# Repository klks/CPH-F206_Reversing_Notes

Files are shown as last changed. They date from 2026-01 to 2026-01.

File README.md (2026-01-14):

# How it started
Late 2025, I came across a Taobao listing that was selling a UHF RFID Reader for less than 10USD, this is fairly uncommon as most readers go for 15+usd onwards. I decided to buy one to add to my reader collection. (I ended up buying 6 units)<br>

<br>

This UHF RFID reader is sold under the model numbers below (with Taobao links)

- [CPH-F206](https://item.taobao.com/item.htm?id=904352296655&skuId=5763416697782)
- [TC-C206](https://item.taobao.com/item.htm?id=820590020134&skuId=5696639435762)
- [BYH-206](https://detail.tmall.com/item.htm?id=986978403603&skuId=5952377616135)

Searching online based on provided software, and screenshots, I was able to track down the company that made the software to [Cykeo](https://www.cykeorfid.com/), they are a company that specializes in making industrial rfid readers and antennas.

# Reader Software
The reader comes with its own software and SDK, and is able to output in multiple formats including Wiegand, Modbus, as well as emulating a USB Keyboard.<br>
<br>
<br>

# PCB Screenshot
Cracking open the reader, we are greeted with a 30mm x 30mm PCB soldered to a another PCB that provides a USB-C connector, a buzzer, and some led's, to keep the PCB compact, 0603 SMD components were used.<br>
<br>

Taking a closer look at the front, we see the MCU and an unknown RF chip has their markings lasered off, and the back has descriptions on what each pin does, what catches my eye is the SWDIO and SWCLK pins, this means theres Serial Wire Debug capabilities, and a chance to dump firmware.<br>
<br>
<br>

# MCU Identification & Firmware Dumping
Before we can attempt to dump the firmware, we'd need to try to figure out what MCU is used, and lucky for us when plugging in the reader the device identifies itself as a N32g43xCustom HID, this led me to believe that the MCU was a [N32G435](https://nsing.com.sg/product/General/cortexm4/N32G435/)

Connecting the SWD header to a J-LINK, setting up its parameters, and attempting to read the firmware, I was able to get a successful dump. Usually MCU's have code readout protection which prevents the downloading of flash contents, the manufacturer did not turn this feature on.

# Firmware Reversing
The firmware can now be thrown into IDA/Ghidra for analysis, using the strings within, around 70% of the firmware can be mapped back to the N32G43x SDK and example implementation found on github. From within the firmware, the RF chip can be identified, they are using an [Si4463](https://www.silabs.com/wireless/proprietary/ezradiopro-sub-ghz-ics/device.si4463?tab=specs) Transceiver chip that supports the ISM band.

<br>
The reversing of the firmware is left as an exercise for the user and will not be covered here.

# PCB Reverse Engineering
The reversing of the PCB would not be possible if the firmware dump was not successful, now that we have the firmware, my next goal is to recreate the PCB but using larger 0805 SMD components.

With PCB reversing, the first steps are component identification, using a hot-plate, components were removed one by one, and their values recorded.<br>

<br>

When dealing with small value components like inductors and capacitors, a Nano-VNA can be used to identify their values.<br>

<br>

# Parts Identification
Identification of parts took a while as finding parts with the same name was challenging. Using part numbers, a multimeter, a component tester, an oscilloscope, image searching and pouring over datasheets helped find most of the components.<br>

<br>

| Marking | Name | Notes |
| --- | ---| --- |
| N32G435 | | MCU <br> [Datasheet](https://www.nsing.com.sg/uploads/DS/EN_DS_N32G435.pdf) |
| Si4463 | | RF Transceiver <br> [Datasheet](https://www.silabs.com/documents/public/data-sheets/Si4463-61-60-C.pdf)|
| 87t | Planar Schottky barrier diode |  [1PS70SB84](https://assets.nexperia.com/documents/data-sheet/1PS70SB82_84_85_86.pdf) (Obsolete), the closest is [BAT54S](https://assets.nexperia.com/documents/data-sheet/BAT54S.pdf) |
| 1F | 45 V, 100 mA NPN/NPN general-purpose transistor | [Datasheet](https://assets.nexperia.com/documents/data-sheet/BC847BS.pdf) |
| -V4 | 2-ch, 1.65-V to 5.5-V inverters | [SN74LVC2G04](https://www.ti.com/lit/ds/symlink/sn74lvc2g04.pdf) |
| AM | NPN switching transistor | [MMBT3904](https://www.onsemi.com/pdf/datasheet/mmbt3904wt1-d.pdf) |
| G4B | RF Switching Diode | No exact match found, the closest is [BAV70](https://assets.nexperia.com/documents/data-sheet/BAV70.pdf)
| N933 | 500mA uCap Ultra-Low Dropout, High PSRR LDO Regulator | [Datasheet](https://ww1.microchip.com/downloads/aemDocuments/documents/OTH/ProductDocuments/DataSheets/500mA-uCap-Ultra-Low-Dropout-Regulator-with-High-PSRR-DS20005876B.pdf) |

For the Si4463 matching and filter network, the datasheet was used to identify the nominal values.

<br>

# Sanding PCB
After the components and their positions have been identified, the solder mask of the PCB is stripped using a 200-600 grit sandpaper to expose the front and back copper layers. This PCB is 4 layers and is 1mm thick.

<br>
<br>

# Tracing PCB
Next using high resolution images, Inkscape, and a multimeter, the traces of the PCB and its via's are drawn in separate layers<br>
This step also maps the MCU and RF pins, an overlay from the datasheet is added for pin identification. The position and values of components measured earlier are also noted, grounds and power lines (5V, 3V3) are color coded.<br>

<br>

<br>

# Reversing PCB & Schematic
Using KiCad, the schematic is then redrawn with their component values. In this step, the component names from KiCad are mapped back to the PCB Trace in Inkscape. Some modifications were made around the USB-C and 3V3 power regulators circuit.

<br>

Schematics are released in the schematic directory of this repo.

# Impedance Matching of RF Trace
When recreating the PCB, KiCad's Calculator Tools and JLCPCB's Capabilities are used to calculate trace width and spacing for the RF trace line.

<br>
<br>

# Ordering & Testing PCB
After weeks of tracing and schematic drawing, PCB's are sent for fabrication. When placing components, i mimicked the layout of the original board, this was done to make circuit debugging easier<br>
<br>
Below is a size comparison of the original and recreated PCB.<br>
<br>
After soldering all the components, the original MCU was soldered on for testing. In the first attempt, the reader was not picking up any tags.<br>
Going back to the drawing board, a few components had to be re-measured from another working reader and a few mistakes were identified. At this point an oscilloscope was used to debug the circuit using references from a functional reader. After fixing mis-typed components and much experimenting, the reader works!.<br>
<br>
One area that needs to be studied more is the matching network and filter sections as the current PCB isn't as fast/sensitive enough at picking up tags vs the original reader.<br>
In v0.2 of the schematic, additional capacitors were added to the 5V rail. Also fixed incorrectly measured value for some components.<br>

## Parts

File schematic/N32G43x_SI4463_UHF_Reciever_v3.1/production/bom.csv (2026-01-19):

Designator | Footprint | Quantity | Value | LCSC Part #
C1, C14, C41, C42, C58 | 0805 | 5 | 100pF
C10, C12, C15, C18, C30, C34, C4, C7 | 0805 | 8 | 2.2nF
C11, C27, C40, C5, C55, C56, C6, C63, C8 | 0805 | 9 | 100nF
C13, C17, C24, C32 | 0805 | 4 | 12pF
C16, C23, C31 | 0805 | 3 | 20pF
C19, C20, C22, C28, C3, C36, C38, C46, C47, C48, C49, C50, C53, C54, C9 | 0805 | 15 | 10uF
C2 | 0805 | 1 | 3.2pF
C21, C37, C51, C52 | 0805 | 4 | 24pF
C25, C29, C33 | 0805 | 3 | 10nF
C26, C35 | 0805 | 2 | 1uF
C39 | 0805 | 1 | 1nF
C43, C44 | 0805 | 2 | 2pF
C45 | 0805 | 1 | 3.3pF
C57, C59, C60, C61, C62 | 1206 | 5 | 10uF
D1, D2 | SOT-23-3_L2.9-W1.6-P1.90-LS2.8-BR | 2 | BAT54S
D3, D4 | 0805 | 2 | LED
D5 | SOT-23-3_L2.9-W1.6-P1.90-LS2.8-BR | 1 | BAR6405
F1 | 0805 | 1 | 6V 0.75A
J1 | IPEX-SMD_BWIPX-1-001E | 1 | U.FL | C5137195
J2, USART1, USART2 | PinHeader_1x04_P2.54mm_Vertical | 3 | Conn_01x04_Socket
J3 | USB-C-SMD_TYPE-C-6PIN-2MD-073 | 1 | USB_C_Receptacle_USB2.0_16P | C2765186
J4 | SolderJumper-2_P1.3mm_Open_RoundedPad1.0x1.5mm | 1 | EN_BUZZ
J5 | PinHeader_1x03_P2.54mm_Vertical | 1 | Conn_01x03_Socket
L1, L2, L5 | 0805 | 3 | 12nH
L3, L4 | 0805 | 2 | 10nH
L6 | 0805 | 1 | 100nH
L7 | 0805 | 1 | 20uH
Q1, Q3, Q4, Q5, Q6, Q7 | SOT-363_SC-70-6 | 6 | BC847BS | C41375126
Q10, Q11, Q2, Q9 | Q_SOT-23 | 4 | MMBT3904 | C7420353
R1, R2, R24, R42, R6 | 0805 | 5 | 1.5k
R10, R7 | 0805 | 2 | R
R11, R12, R18, R19 | 0805 | 4 | 750
R13, R14 | 0805 | 2 | 2k
R15, R17, R30, R40, R41 | 0805 | 5 | 5.1k
R16, R22, R31 | 0805 | 3 | 30
R20, R35, R4, R5, R8, R9 | 0805 | 6 | 4.7k
R21, R23, R25, R32, R33, R43 | 0805 | 6 | 10k
R26, R27 | 0805 | 2 | 1M
R28, R29 | 0805 | 2 | 3k
R3 | 0805 | 1 | 560
R34, R36 | 0805 | 2 | 0R
R37, R38, R39, R45, R46 | 0805 | 5 | 1k
R44 | 0805 | 1 | 100R
TP1 | TestPoint_Pad_D1.5mm | 1 | T+
TP2 | TestPoint_Pad_D1.5mm | 1 | J1
TP5 | TestPoint_Pad_D1.5mm | 1 | 485-EN
TP6 | TestPoint_Pad_D1.5mm | 1 | J2
TP7 | TestPoint_Pad_D1.5mm | 1 | 3V3
TP8 | TestPoint_Pad_D1.5mm | 1 | 5V
TP9 | TestPoint_Pad_D1.5mm | 1 | GND
U1 | QFN-20-1EP_4x4mm_P0.5mm_EP2.6x2.6mm_ThermalVias | 1 | Si4463
U2 | LQFP-48_7x7mm_P0.5mm | 1 | N32G435_LQFP48 | C8734
U3 | TSOP-5_1.65x3.05mm_P0.95mm | 1 | RT9013
U4 | SOT-23-6_L2.9-W1.6-P0.95-LS2.8-BR | 1 | SN74LVC2G04DBVR | C10428
U5 | SOT-23-6 | 1 | USBLC6-2SC6
U6 | BUZ-TH_BD9.0-P5.00-D0.6-FD | 1 | HYT-0905_C7544823 | C7544823
X1, X2 | OSC-SMD_4P-L3.2-W2.5-BL | 2 | X322525MOB4SI | C9006

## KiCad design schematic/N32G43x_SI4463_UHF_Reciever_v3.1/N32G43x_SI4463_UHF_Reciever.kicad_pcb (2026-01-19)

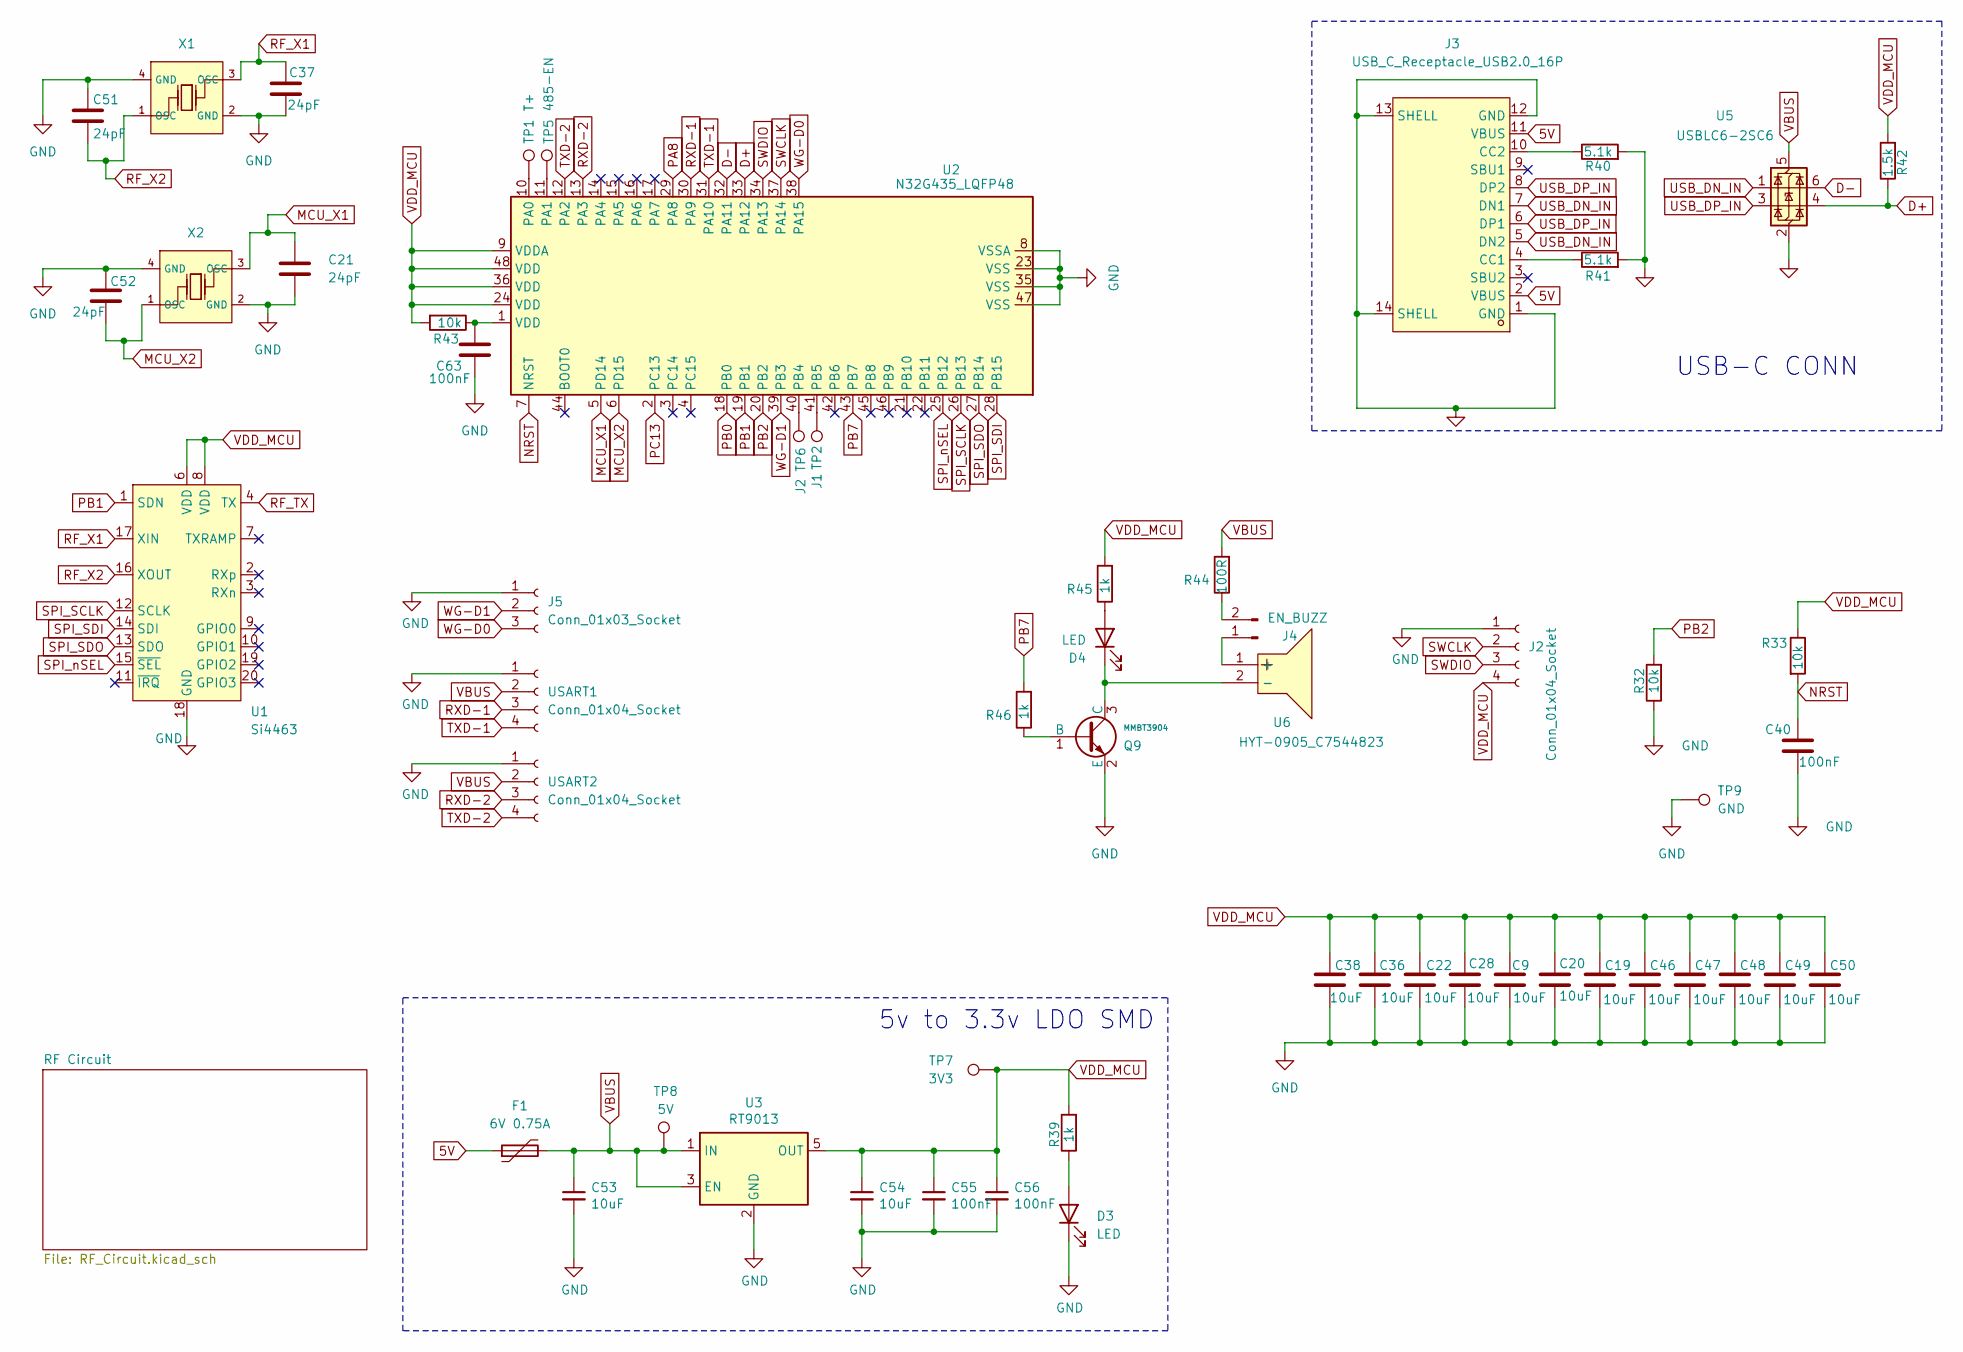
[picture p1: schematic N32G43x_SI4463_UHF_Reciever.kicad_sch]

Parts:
C9, C19, C20, C22, C28, C36, C38, C46, C47, C48, C49, C50, C53, C54: 10uF; C_0805_2012Metric_Pad1.18x1.45mm_HandSolder
C21, C37, C51, C52: 24pF; C_0805_2012Metric_Pad1.18x1.45mm_HandSolder
C40, C55, C56, C63: 100nF; C_0805_2012Metric_Pad1.18x1.45mm_HandSolder
D3, D4: LED; LED_0805_2012Metric_Pad1.15x1.40mm_HandSolder
F1: 6V 0.75A; Fuse_0805_2012Metric_Pad1.15x1.40mm_HandSolder
J2: Conn_01x04_Socket; PinHeader_1x04_P2.54mm_Vertical
J3: USB_C_Receptacle_USB2.0_16P; USB-C-SMD_TYPE-C-6PIN-2MD-073; LCSC Part C2765186
J4: EN_BUZZ; SolderJumper-2_P1.3mm_Open_RoundedPad1.0x1.5mm
J5: Conn_01x03_Socket; PinHeader_1x03_P2.54mm_Vertical
Q9: MMBT3904; Q_SOT-23; Part MMBT3904; LCSC C7420353
R32, R33, R43: 10k; R_0805_2012Metric_Pad1.20x1.40mm_HandSolder
R39, R45, R46: 1k; R_0805_2012Metric_Pad1.20x1.40mm_HandSolder
R40, R41: 5.1k; R_0805_2012Metric_Pad1.20x1.40mm_HandSolder
R42: 1.5k; R_0805_2012Metric_Pad1.20x1.40mm_HandSolder
R44: 100R; R_0805_2012Metric_Pad1.20x1.40mm_HandSolder
TP1: T+; TestPoint_Pad_D1.5mm
TP2: J1; TestPoint_Pad_D1.5mm
TP5: 485-EN; TestPoint_Pad_D1.5mm
TP6: J2; TestPoint_Pad_D1.5mm
TP7: 3V3; TestPoint_Pad_D1.5mm
TP8: 5V; TestPoint_Pad_D1.5mm
TP9: GND; TestPoint_Pad_D1.5mm
U1: Si4463; QFN-20-1EP_4x4mm_P0.5mm_EP2.6x2.6mm_ThermalVias
U2: N32G435_LQFP48; LQFP-48_7x7mm_P0.5mm; Operating Voltage Range 2V~3.6V; Low Voltage Detection T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 2V~3.6V; Part STM32F103C8T6; LCSC C8734
U3: RT9013; TSOP-5_1.65x3.05mm_P0.95mm
U5: USBLC6-2SC6; SOT-23-6
U6: HYT-0905_C7544823; BUZ-TH_BD9.0-P5.00-D0.6-FD; LCSC Part C7544823
USART1, USART2: Conn_01x04_Socket; PinHeader_1x04_P2.54mm_Vertical
X1, X2: X322525MOB4SI; OSC-SMD_4P-L3.2-W2.5-BL; Frequency Tolerance ±10ppm; Part X322525MOB4SI; LCSC C9006

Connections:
5V: F1.1, J3.2 (VBUS), J3.11 (VBUS)
D+: R42.1, U2.33 (PA12), U5.4 (I/O2)
D-: U2.32 (PA11), U5.6 (I/O1)
MCU_X1: C21.1, U2.5 (PD14), X2.3 (OSC)
MCU_X2: C52.2, U2.6 (PD15), X2.1 (OSC)
NRST: C40.2, R33.2, U2.7 (NRST)
unnamed: C63.1, R43.1, U2.1 (VDD)
unnamed: D3.2 (A), R39.1
unnamed: D4.2 (A), R45.1
unnamed: D4.1 (K), Q9.3 (C), U6.2 (-)
unnamed: J3.4 (CC1), R41.1
unnamed: J3.10 (CC2), R40.1
unnamed: J4.1, U6.1 (+)
unnamed: J4.2, R44.1
unnamed: Q9.1 (B), R46.1
unnamed: TP1.1, U2.10 (PA0)
unnamed: TP5.1, U2.11 (PA1)
unnamed: TP6.1, U2.40 (PB4)
unnamed: TP2.1, U2.41 (PB5)
PA8: U2.29 (PA8); also elsewhere on the board
PB0: U2.18 (PB0); also elsewhere on the board
PB1: U1.1 (SDN), U2.19 (PB1)
PB2: R32.2, U2.20 (PB2)
PB7: R46.2, U2.43 (PB7)
PC13: U2.2 (PC13); also elsewhere on the board
RF_TX: U1.4 (TX); also elsewhere on the board
RF_X1: C37.1, U1.17 (XIN), X1.3 (OSC)
RF_X2: C51.2, U1.16 (XOUT), X1.1 (OSC)
RXD-1: U2.30 (PA9), USART1.3
RXD-2: U2.13 (PA3), USART2.3
SPI_SCLK: U1.12 (SCLK), U2.26 (PB13)
SPI_SDI: U1.14 (SDI), U2.28 (PB15)
SPI_SDO: U1.13 (SDO), U2.27 (PB14)
SPI_nSEL: U1.15 (~SEL), U2.25 (PB12)
SWCLK: J2.2, U2.37 (PA14)
SWDIO: J2.3, U2.34 (PA13)
TXD-1: U2.31 (PA10), USART1.4
TXD-2: U2.12 (PA2), USART2.4
USB_DN_IN: J3.5 (DN2), J3.7 (DN1), U5.1 (I/O1)
USB_DP_IN: J3.6 (DP1), J3.8 (DP2), U5.3 (I/O2)
VBUS: C53.1, F1.2, R44.2, TP8.1, U3.1 (IN), U3.3 (EN), U5.5 (VBUS), USART1.2, USART2.2; also elsewhere on the board
VDD_MCU: C9.2, C19.1, C20.1, C22.1, C28.2, C36.1, C38.1, C46.1, C47.1, C48.1, C49.1, C50.1, C54.1, C55.1, C56.1, J2.4, R33.1, R39.2, R42.2, R43.2, R45.2, TP7.1, U1.6 (VDD), U1.8 (VDD), U2.9 (VDDA), U2.24 (VDD), U2.36 (VDD), U2.48 (VDD), U3.5 (OUT); also elsewhere on the board
WG-D0: J5.3, U2.38 (PA15)
WG-D1: J5.2, U2.39 (PB3)

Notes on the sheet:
5v to 3.3v LDO SMD
USB-C CONN

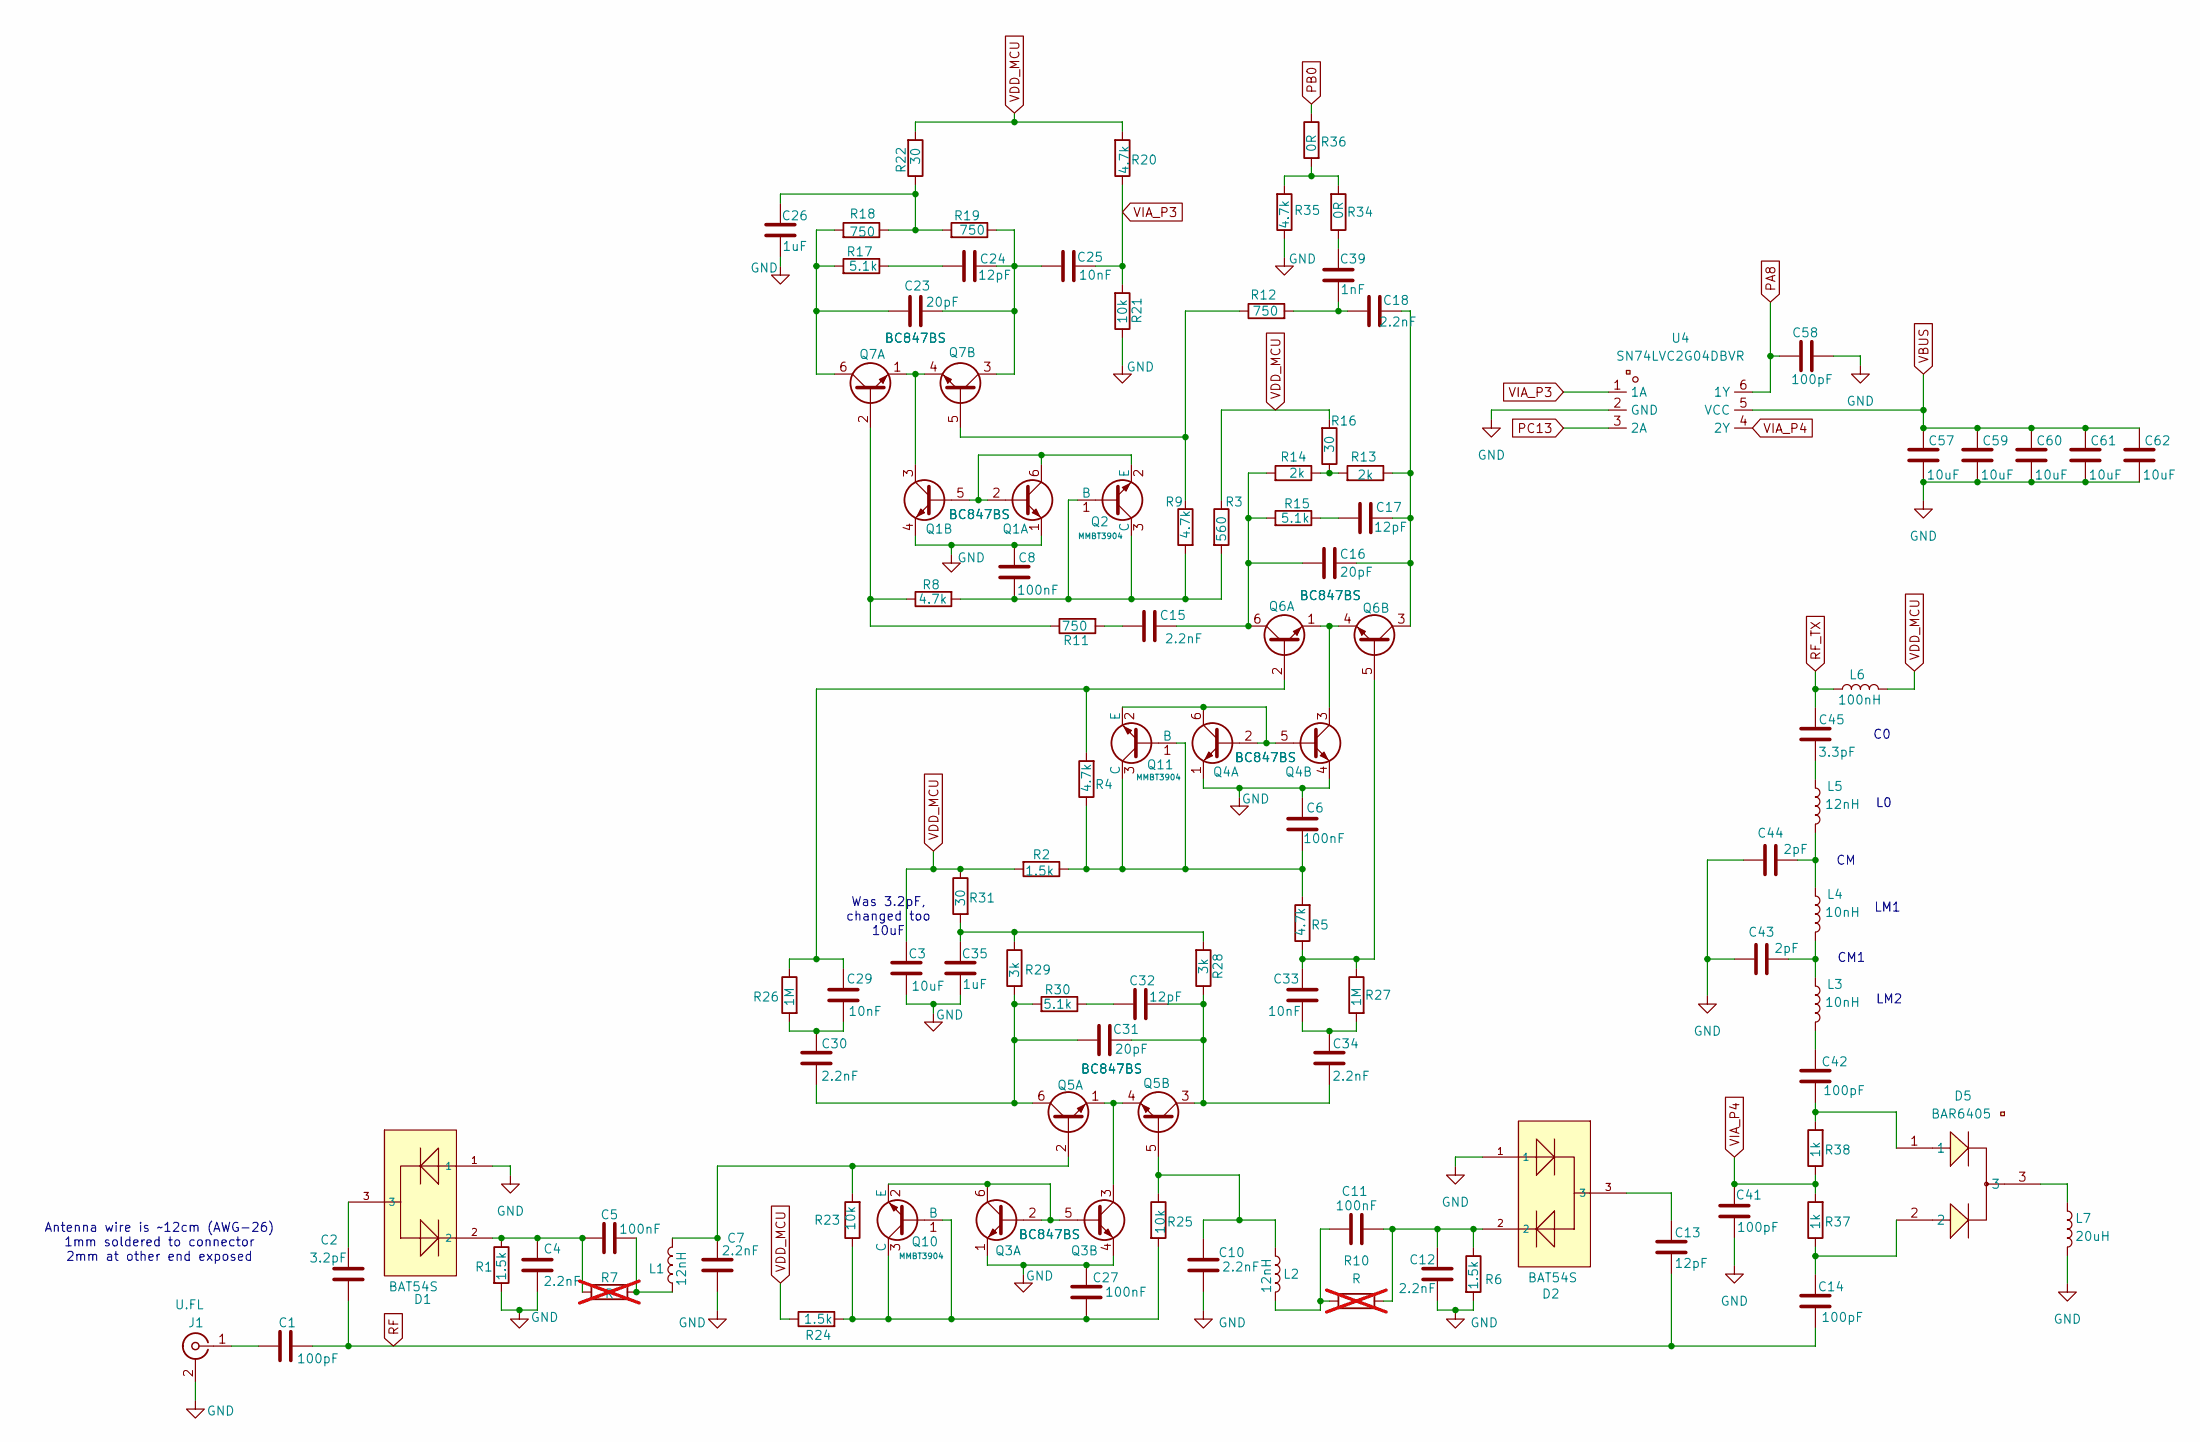
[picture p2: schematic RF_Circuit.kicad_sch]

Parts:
C1, C14, C41, C42, C58: 100pF; C_0805_2012Metric_Pad1.18x1.45mm_HandSolder
C2: 3.2pF; C_0805_2012Metric_Pad1.18x1.45mm_HandSolder
C3: 10uF; C_0805_2012Metric_Pad1.18x1.45mm_HandSolder
C4, C7, C10, C12, C15, C18, C30, C34: 2.2nF; C_0805_2012Metric_Pad1.18x1.45mm_HandSolder
C5, C6, C8, C11, C27: 100nF; C_0805_2012Metric_Pad1.18x1.45mm_HandSolder
C13, C17, C24, C32: 12pF; C_0805_2012Metric_Pad1.18x1.45mm_HandSolder
C16, C23, C31: 20pF; C_0805_2012Metric_Pad1.18x1.45mm_HandSolder
C25, C29, C33: 10nF; C_0805_2012Metric_Pad1.18x1.45mm_HandSolder
C26, C35: 1uF; C_0805_2012Metric_Pad1.18x1.45mm_HandSolder
C39: 1nF; C_0805_2012Metric_Pad1.18x1.45mm_HandSolder
C43, C44: 2pF; C_0805_2012Metric_Pad1.18x1.45mm_HandSolder
C45: 3.3pF; C_0805_2012Metric_Pad1.18x1.45mm_HandSolder
C57, C59, C60, C61, C62: 10uF; C_1206_3216Metric_Pad1.33x1.80mm_HandSolder
D1, D2: BAT54S; SOT-23-3_L2.9-W1.6-P1.90-LS2.8-BR; Reverse Voltage (Vr) 100V; Forward Voltage (Vf@If) 1.25V@150mA; Part BAV99,215
D5: BAR6405; SOT-23-3_L2.9-W1.6-P1.90-LS2.8-BR
J1: U.FL; IPEX-SMD_BWIPX-1-001E; LCSC C5137195
L1, L2, L5: 12nH; L_0805_2012Metric_Pad1.05x1.20mm_HandSolder
L3, L4: 10nH; L_0805_2012Metric_Pad1.05x1.20mm_HandSolder
L6: 100nH; L_0805_2012Metric_Pad1.05x1.20mm_HandSolder
L7: 20uH; L_0805_2012Metric_Pad1.05x1.20mm_HandSolder
Q1, Q3, Q4, Q5, Q6, Q7: BC847BS; SOT-363_SC-70-6; Part BC847BS; LCSC C41375126
Q2, Q10, Q11: MMBT3904; Q_SOT-23; Part MMBT3904; LCSC C7420353
R1, R2, R6, R24: 1.5k; R_0805_2012Metric_Pad1.20x1.40mm_HandSolder
R3: 560; R_0805_2012Metric_Pad1.20x1.40mm_HandSolder
R4, R5, R8, R9, R20, R35: 4.7k; R_0805_2012Metric_Pad1.20x1.40mm_HandSolder
R7, R10: R; R_0805_2012Metric_Pad1.20x1.40mm_HandSolder; not fitted
R11, R12, R18, R19: 750; R_0805_2012Metric_Pad1.20x1.40mm_HandSolder
R13, R14: 2k; R_0805_2012Metric_Pad1.20x1.40mm_HandSolder
R15, R17, R30: 5.1k; R_0805_2012Metric_Pad1.20x1.40mm_HandSolder
R16, R22, R31: 30; R_0805_2012Metric_Pad1.20x1.40mm_HandSolder
R21, R23, R25: 10k; R_0805_2012Metric_Pad1.20x1.40mm_HandSolder
R26, R27: 1M; R_0805_2012Metric_Pad1.20x1.40mm_HandSolder
R28, R29: 3k; R_0805_2012Metric_Pad1.20x1.40mm_HandSolder
R34, R36: 0R; R_0805_2012Metric_Pad1.20x1.40mm_HandSolder
R37, R38: 1k; R_0805_2012Metric_Pad1.20x1.40mm_HandSolder
U4: SN74LVC2G04DBVR; SOT-23-6_L2.9-W1.6-P0.95-LS2.8-BR; LCSC Part C10428

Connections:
unnamed: C2.2, D1.3
unnamed: C4.2, C5.2, D1.2, R1.1, R7.1
unnamed: C5.1, L1.1, R7.2
unnamed: C11.1, C12.2, D2.2, R6.1, R10.2
unnamed: C11.2, L2.2, R10.1
unnamed: C13.2, D2.3
unnamed: C14.1, D5.2, R37.1
unnamed: C15.2, R11.2
unnamed: C17.1, R15.1
unnamed: C18.2, C39.2, R12.2
unnamed: C24.1, R17.1
unnamed: C26.1, R18.1, R19.2, R22.1
unnamed: C29.1, C30.2, R26.2
unnamed: C32.1, R30.1
unnamed: C33.1, C34.2, R27.2
unnamed: C35.1, R28.2, R29.1, R31.2
unnamed: C39.1, R34.1
unnamed: C42.1, L3.2
unnamed: C42.2, D5.1, R38.2
unnamed: C43.1, L3.1, L4.2
unnamed: C44.1, L4.1, L5.2
unnamed: C45.2, L5.1
unnamed: D5.3, L7.1
unnamed: C1.2, J1.1 (In)
unnamed: Q1.2 (B1), Q1.5 (B2), Q1.6 (C1), Q2.2 (E)
unnamed: Q1.3 (C2), Q7.1 (E1), Q7.4 (E2)
unnamed: C8.1, Q2.1 (B), Q2.3 (C), R3.2, R8.2, R9.2
unnamed: Q3.3 (C2), Q5.1 (E1), Q5.4 (E2)
unnamed: Q4.3 (C2), Q6.1 (E1), Q6.4 (E2)
unnamed: C7.2, L1.2, Q5.2 (B1), R23.2
unnamed: C30.1, C31.1, Q5.6 (C1), R29.2, R30.2
unnamed: C10.2, L2.1, Q5.5 (B2), R25.1
unnamed: C31.2, C32.2, C34.1, Q5.3 (C2), R28.1
unnamed: C29.2, Q6.2 (B1), R4.2, R26.1
unnamed: C15.1, C16.1, Q6.6 (C1), R14.2, R15.2
unnamed: C33.2, Q6.5 (B2), R5.1, R27.1
unnamed: C16.2, C17.2, C18.1, Q6.3 (C2), R13.1
unnamed: Q7.2 (B1), R8.1, R11.1
unnamed: C23.1, Q7.6 (C1), R17.2, R18.2
unnamed: Q7.5 (B2), R9.1, R12.1
unnamed: C23.2, C24.2, C25.1, Q7.3 (C2), R19.1
unnamed: C27.2, Q10.1 (B), Q10.3 (C), R23.1, R24.2, R25.2
unnamed: Q3.2 (B1), Q3.5 (B2), Q3.6 (C1), Q10.2 (E)
unnamed: C6.1, Q11.1 (B), Q11.3 (C), R2.1, R4.1, R5.2
unnamed: Q4.2 (B1), Q4.5 (B2), Q4.6 (C1), Q11.2 (E)
unnamed: R13.2, R14.1, R16.1
unnamed: R34.2, R35.2, R36.2
PA8: C58.1, U4.6 (1Y); also elsewhere on the board
PB0: R36.1; also elsewhere on the board
PC13: U4.3 (2A); also elsewhere on the board
RF: C1.1, C2.1, C13.1, C14.2
RF_TX: C45.1, L6.1; also elsewhere on the board
VBUS: C57.1, C59.1, C60.1, C61.1, C62.1, U4.5 (VCC); also elsewhere on the board
VDD_MCU: C3.2, L6.2, R2.2, R3.1, R16.2, R20.2, R22.2, R24.1, R31.1; also elsewhere on the board
VIA_P3: C25.2, R20.1, R21.2, U4.1 (1A)
VIA_P4: C41.1, R37.2, R38.1, U4.4 (2Y)

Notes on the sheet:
LM1
LM2
Was 3.2pF, changed too 10uF
Antenna wire is ~12cm (AWG-26) 1mm soldered to connector 2mm at other end exposed
CM1

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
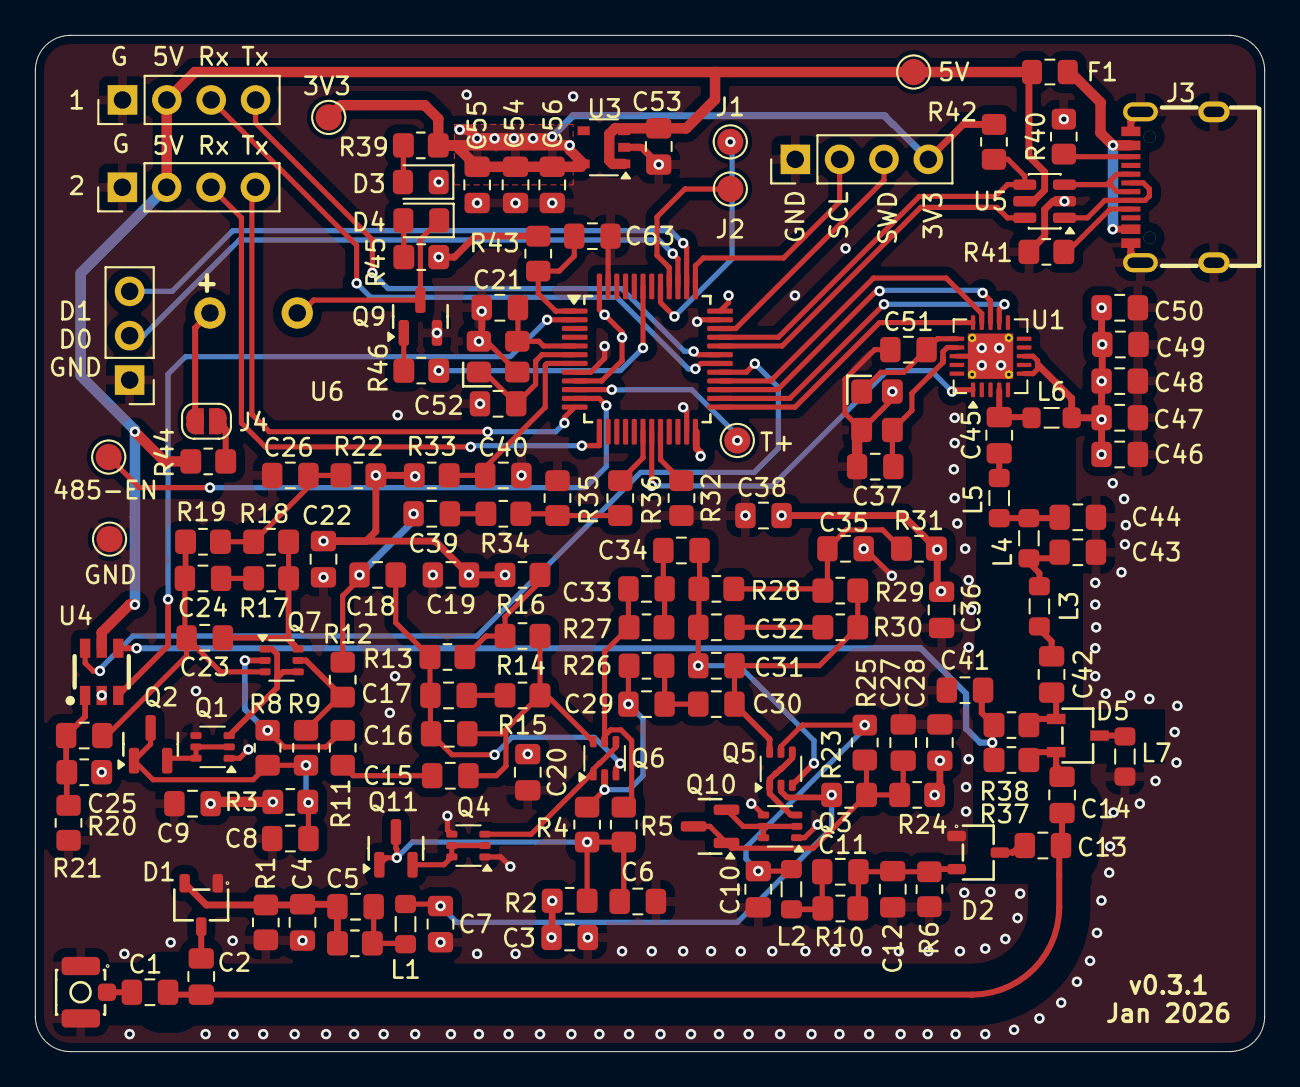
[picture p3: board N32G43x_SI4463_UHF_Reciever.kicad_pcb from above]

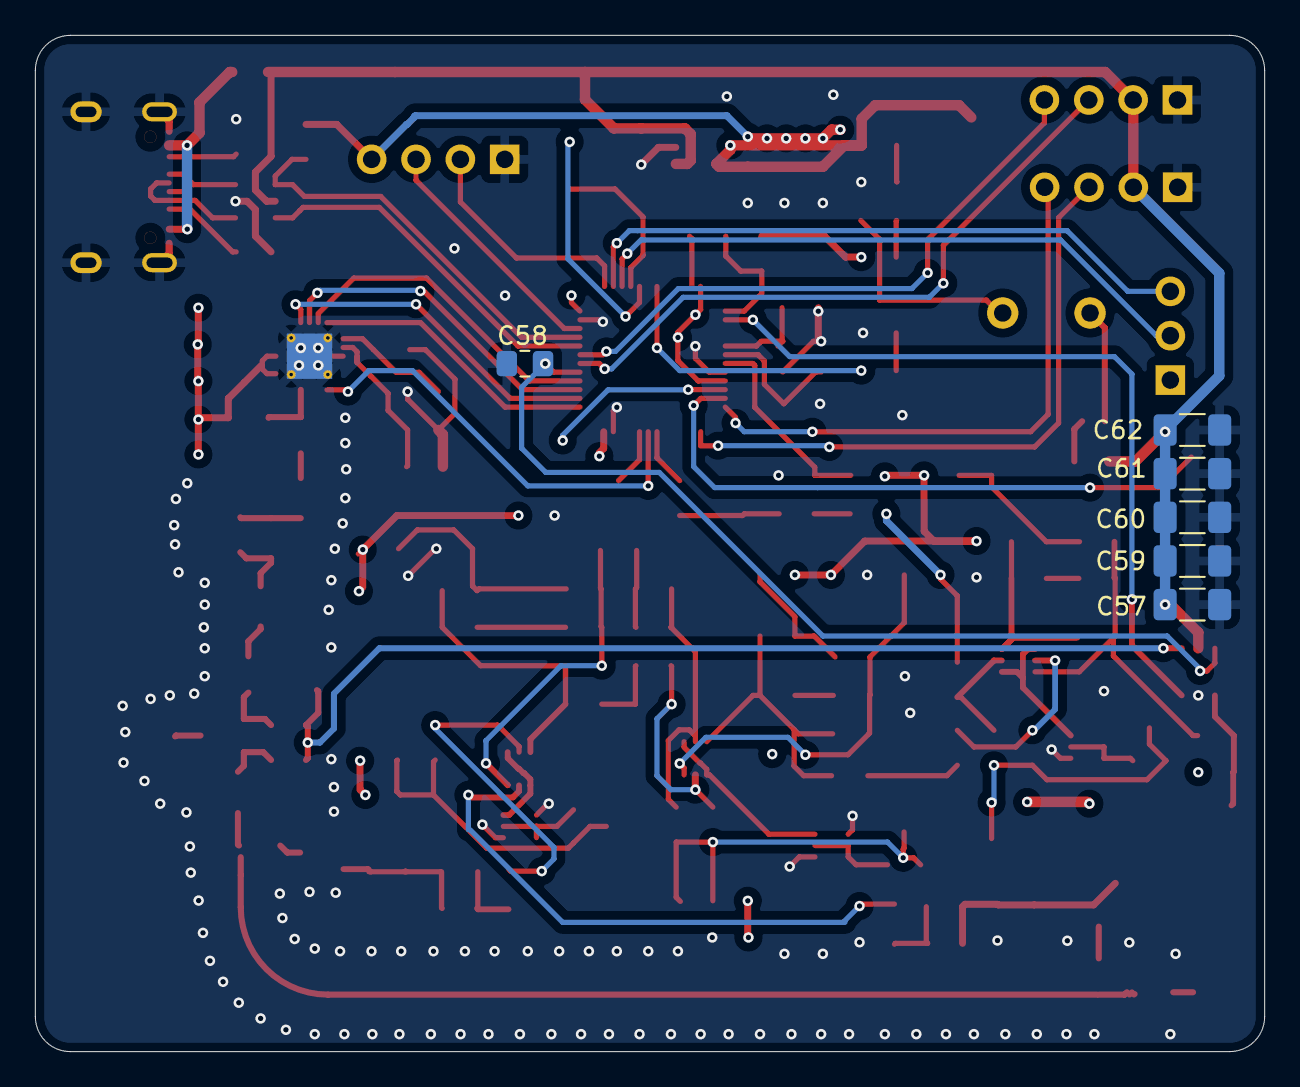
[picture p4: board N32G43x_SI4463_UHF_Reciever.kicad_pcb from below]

Board: 4 copper layers, 70.4 x 58.2 mm, 154 parts (6 on the bottom side), 95 nets.

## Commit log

2026-01-11 Minor update to match pcb
    [N32G43x_SI4463_UHF_Reciever.kicad_pcb, RF_Circuit.kicad_sch]
2026-01-19 Update schematic to v3.1
    [N32G43x_SI4463_UHF_Reciever.kicad_pcb, N32G43x_SI4463_UHF_Reciever.kicad_sch, RF_Circuit.kicad_sch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]
